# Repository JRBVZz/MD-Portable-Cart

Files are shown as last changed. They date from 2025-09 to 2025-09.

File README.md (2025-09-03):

#### Картридж для карманной консоли MD Portable

В основе картриджа одна микросхема Flash ROM в корпусе TSOP48 или TSOP56, в зависимости от объема памяти. Для прошивки игры нужен отдельный программатор.

ВНИМАНИЕ, сторона с чипом памяти является обратной стороной по отношению к экрану MD Portable.
Многоигровки на Flash объемом 8МБ и выше не тестировались.

Проект создан в [**KiCad 9**](https://www.kicad.org/).

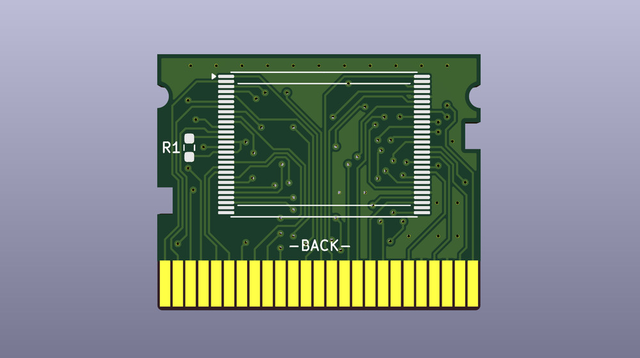
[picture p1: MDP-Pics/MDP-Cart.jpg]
3D Bottom


#### Параметры для изготовления PCB
* 2 слоя
* Толщина PCB: 1.2 мм
* Рекомендуется ENIG покрытие контактов краевого разъема

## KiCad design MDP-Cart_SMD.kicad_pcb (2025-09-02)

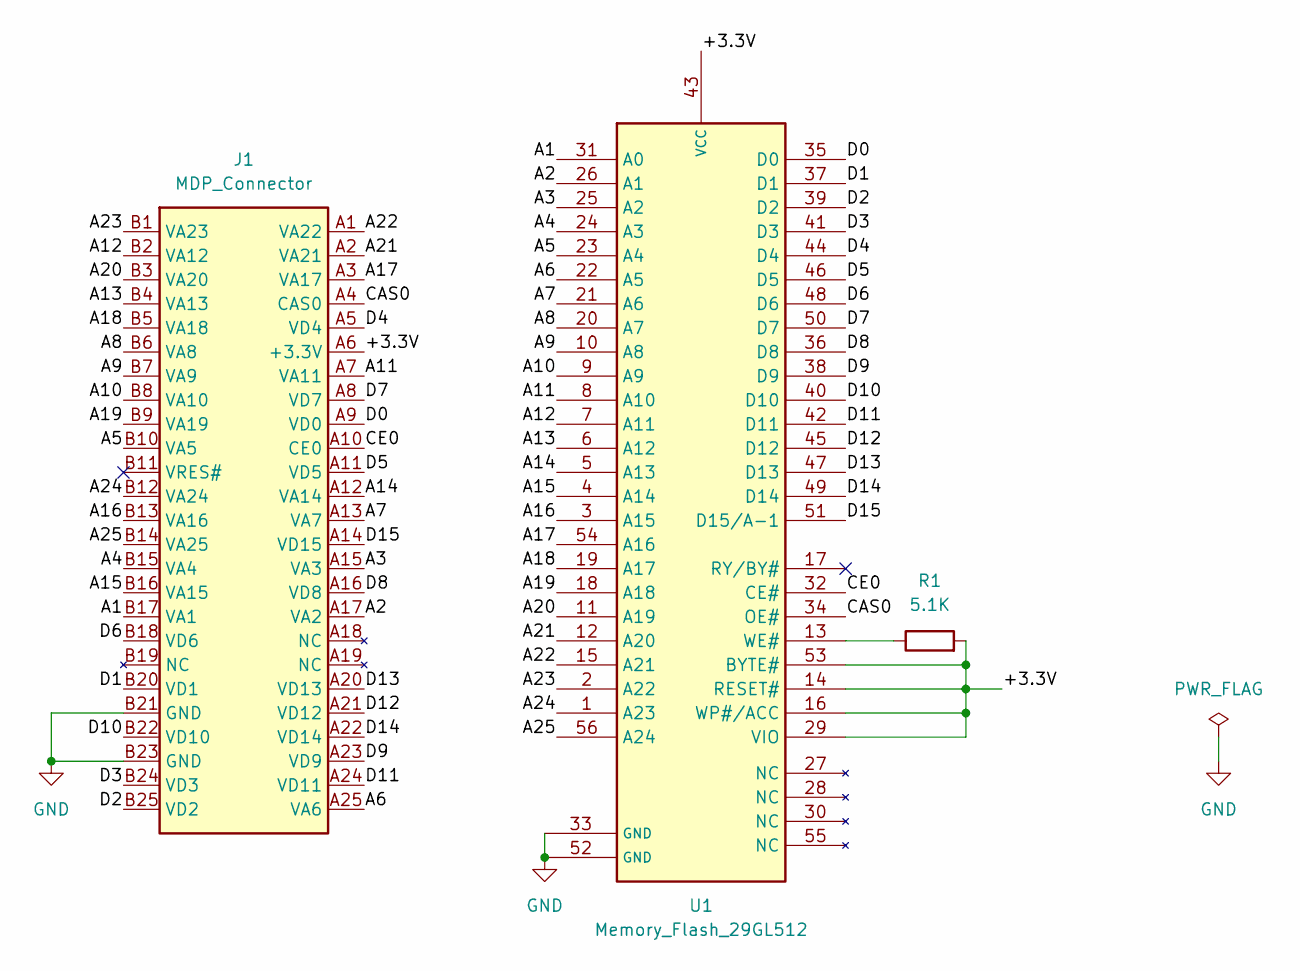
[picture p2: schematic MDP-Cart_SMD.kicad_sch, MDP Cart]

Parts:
J1: MDP_Connector
R1: 5.1K; R_0603_1608Metric_Pad0.98x0.95mm_HandSolder
U1: Memory_Flash_29GL512; TSOP-I-56_18.4x14mm_P0.5mm

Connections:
/+3.3V: J1.A6 (+3.3V), R1.2, U1.14 (RESET#), U1.16 (WP#/ACC), U1.29 (VIO), U1.43 (VCC), U1.53 (BYTE#)
/A1: J1.B17 (VA1), U1.31 (A0)
/A2: J1.A17 (VA2), U1.26 (A1)
/A3: J1.A15 (VA3), U1.25 (A2)
/A4: J1.B15 (VA4), U1.24 (A3)
/A5: J1.B10 (VA5), U1.23 (A4)
/A6: J1.A25 (VA6), U1.22 (A5)
/A7: J1.A13 (VA7), U1.21 (A6)
/A8: J1.B6 (VA8), U1.20 (A7)
/A9: J1.B7 (VA9), U1.10 (A8)
/A10: J1.B8 (VA10), U1.9 (A9)
/A11: J1.A7 (VA11), U1.8 (A10)
/A12: J1.B2 (VA12), U1.7 (A11)
/A13: J1.B4 (VA13), U1.6 (A12)
/A14: J1.A12 (VA14), U1.5 (A13)
/A15: J1.B16 (VA15), U1.4 (A14)
/A16: J1.B13 (VA16), U1.3 (A15)
/A17: J1.A3 (VA17), U1.54 (A16)
/A18: J1.B5 (VA18), U1.19 (A17)
/A19: J1.B9 (VA19), U1.18 (A18)
/A20: J1.B3 (VA20), U1.11 (A19)
/A21: J1.A2 (VA21), U1.12 (A20)
/A22: J1.A1 (VA22), U1.15 (A21)
/A23: J1.B1 (VA23), U1.2 (A22)
/A24: J1.B12 (VA24), U1.1 (A23)
/A25: J1.B14 (VA25), U1.56 (A24)
/CAS0: J1.A4 (CAS0), U1.34 (OE#)
/CE0: J1.A10 (CE0), U1.32 (CE#)
/D0: J1.A9 (VD0), U1.35 (D0)
/D1: J1.B20 (VD1), U1.37 (D1)
/D2: J1.B25 (VD2), U1.39 (D2)
/D3: J1.B24 (VD3), U1.41 (D3)
/D4: J1.A5 (VD4), U1.44 (D4)
/D5: J1.A11 (VD5), U1.46 (D5)
/D6: J1.B18 (VD6), U1.48 (D6)
/D7: J1.A8 (VD7), U1.50 (D7)
/D8: J1.A16 (VD8), U1.36 (D8)
/D9: J1.A23 (VD9), U1.38 (D9)
/D10: J1.B22 (VD10), U1.40 (D10)
/D11: J1.A24 (VD11), U1.42 (D11)
/D12: J1.A21 (VD12), U1.45 (D12)
/D13: J1.A20 (VD13), U1.47 (D13)
/D14: J1.A22 (VD14), U1.49 (D14)
/D15: J1.A14 (VD15), U1.51 (D15/A-1)
GND: J1.B21 (GND), J1.B23 (GND), U1.33 (GND), U1.52 (GND)
unnamed: R1.1, U1.13 (WE#)

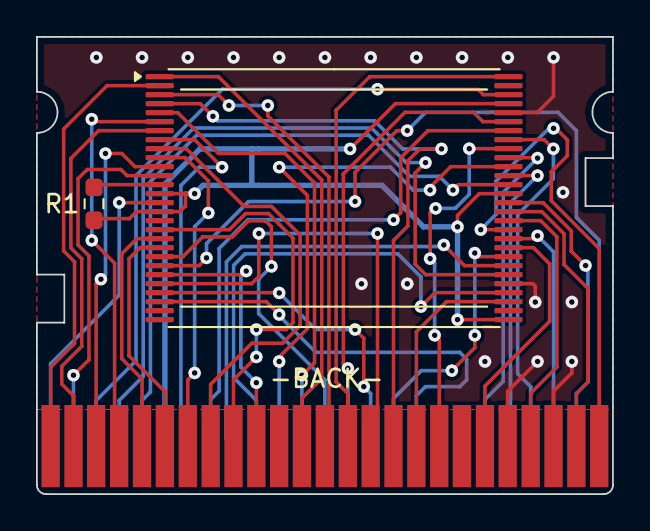
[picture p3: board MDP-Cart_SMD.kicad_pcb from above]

Board: 2 copper layers, 32.0 x 25.4 mm, 3 parts (0 on the bottom side), 46 nets.
